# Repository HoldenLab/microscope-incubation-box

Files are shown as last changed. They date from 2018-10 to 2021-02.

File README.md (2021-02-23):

## This box has been superseded by the LifeHack repository (Incubation Box). Documentation is available on the <a href="https://holdenlab.github.io/LifeHackWebsite/">LifeHack website</a>.

Microscope incubation box for home built single molecule microscope.
Designed in AutoDesk CAD software.

Designed by Dr Yann Cesbron, Holden Lab

We heat this system with a high precision temperature control system, "The Cube" from http://lis.ch/, which we have found to be stabe to < 0.1C.

The body plastic is 10mm Black 9961 Perspex and the Front Panel Top Window is 10mm Clear Perspex.

Fabrication was by a local company, Bay Plastics Ltd, North Shields, UK and cost £1350 inc. materials. 

See LICENSE.txt for license information.

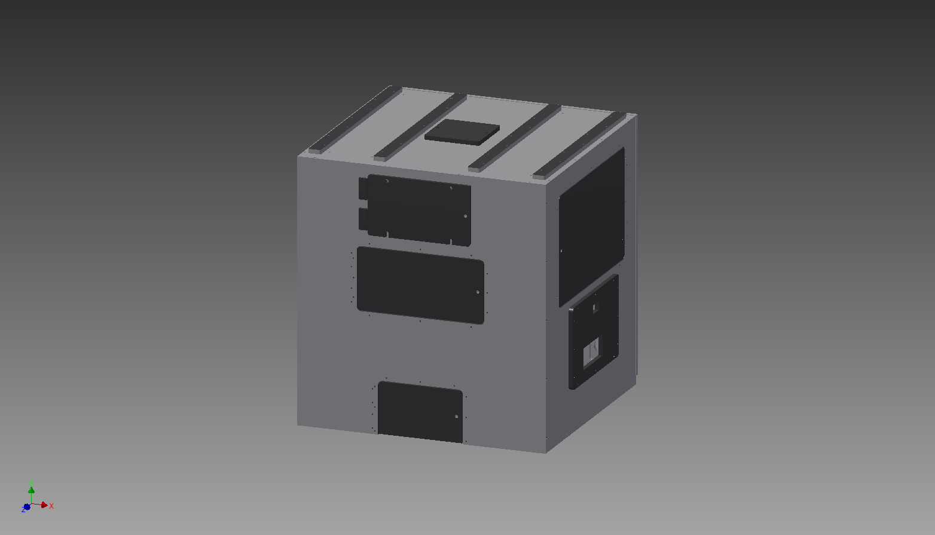
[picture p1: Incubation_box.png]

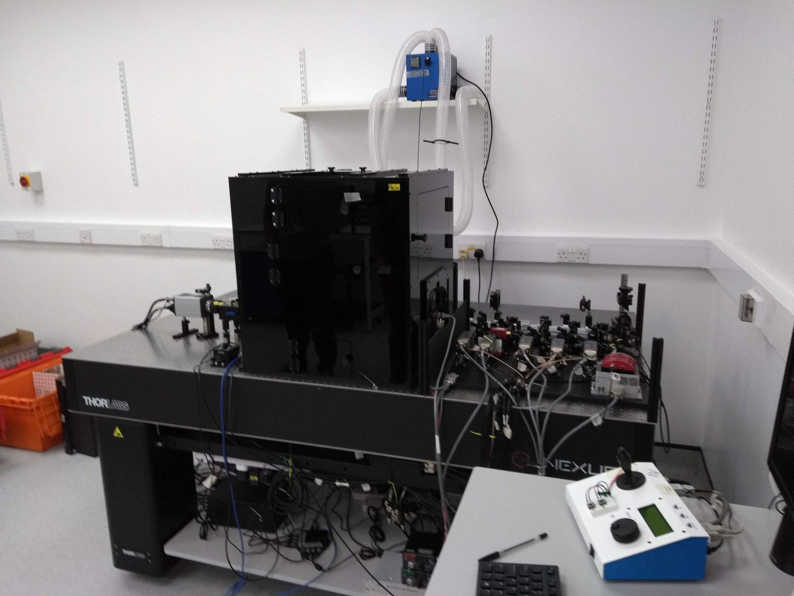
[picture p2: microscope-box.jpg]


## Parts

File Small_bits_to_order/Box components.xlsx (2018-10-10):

Component | Price | Screw | Company | Stock no.
Southco Black Nylon Torque-Adjustable Hinge Screw, 49mm x 44mm x 7mm | £8.34 | 4.5 mm | RS | 268-2086
Eclipse 5mm Neodymium Disc Magnet | £5.24 | Magnet diameter: 5mm/ Length: 2mm | RS | 792-4559
Elesa Black Polymer Knob 69893, M6 x 18 | £1.71 | M6 screw Thread | RS | 290-3743
HI-TORQUE Stainless Steel with Slotted Hex Head Hose Clip Worm Drive, 16mm Band Width, 50mm - 70mm Inside Diameter | £4.85 |  | RS | 494-2172
White extruded PVC sheet 2mm thickness (2440m x 1220 mm) (020XTPVCWHITE) | £30.87 |  | Bay Plastics Ltd
Black Natural Rubber Sheets, 1000mm x 600mm x 1.5mm | £9.08 |  | RS | 506-3078
50 x 20mm 2 Hole Steel Angle Bracket, 2mm Thickness | £2.26 | 4.5 mm screw holes (needs enlarging) | RS | 387-4028
15 x 25mm 2 Hole Steel Angle Bracket, 1.2mm Thickness | £0.23 | 3.7mm screw holes (may need enlarging) | RS | 427-997
RS Pro Clear Passivated, Zinc Steel Self-Clinching Nut, M4 | £6.16 | M4 holes | RS | 827-647
RS Pro Steel Zinc Plated Self-Clinching Standoff, M4 | £25.04 | M4 holes | RS | 827-518
RS Pro Brass Insert, M4 | £15.10 | M4 holes | RS | 278-607

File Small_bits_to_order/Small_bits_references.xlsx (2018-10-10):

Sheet: Materials_list_small_bits
 |  | Supplier | Ref | Name | Unit price | # |  |  | Note: where
Hinges
 |  | RS | 268-2086 | Southco Black Nylon Torque-Adjustable Hinge Screw, 49mm x 44mm x 7mm | 8.34 | 10 | 83.4 |  | Front: 3x2; left: 2; right: 2
 |  |  |  |  |  |  | 0
Door knob
 | option 1 | RS | 448-8858 | Elesa Black Polymer Knob, M6 x 12 | 1.327 | 10 | 13.27 |  | M6
 | option 2 | RS | 686-020 | RS Pro Black Duroplast Knob | 0.846 |  | 0 |  | M6
 | option 3 | RS | 290-3743 | Elesa Black Polymer Knob 69893, M6 x 18 | 1.708 |  | 0 |  | nope, too big
 | option 4 | RS | 448-8820 | Elesa Black Polymer Knob, M4 x 10 | 1.192 |  | 0 |  | M4
 | option 5 | RS | 448-8820 | Elesa Black Polypropylene (PP) Knob 26661, M4 x 8 | 4.75 |  | 0 |  | M4
Cover knobs
 |  | RS | 702-7557 | RS Pro Duroplast Knob, M6 x 20 | 1.587 | 10 | 15.87 |  | Front: 4; top: 2
 |  |  |  |  |  |  | 0
 |  |  |  |  |  |  | 0
Door screws |  |  |  |  |  |  | 0
 |  | RS | 232-8467 | Hex Socket Countersunk Stainless Steel Plain Socket Screw, M6 x 16mm | 11.32 | 1 | 11.32 |  | Box of 50
Bracket
 |  | RS | 427-997 | 15 x 25mm 2 Hole Steel Angle Bracket, 1.2mm Thickness | 0.246 | 10 | 2.46
 |  | RS | 387-4028 | 50 x 20mm 2 Hole Steel Angle Bracket, 2mm Thickness | 2.26 | 4 | 9.04
 |  |  |  |  |  |  | 0
Rubber |  |  |  |  |  |  | 0
 |  | RS | 506-3163 | Black Neoprene Rubber Sheets, 1000mm x 600mm x 1.5mm | 7.86 | 1 | 7.86 |  | To go around side and back holes around optics/electronics
 |  | RS | 733-6731 | Black Neoprene Rubber Sponge, 1000mm x 2000mm x 1.5mm | 8.16 | 1 | 8.16 |  | To go around front top door
 |  | RS | 506-3078 | Black Natural Rubber Sheets, 1000mm x 600mm x 1.5mm | 9.08 | 1 | 9.08
Magnets
 |  | RS | 846-3806 | Eclipse 6mm Alnico Deep Pot Magnet | 6.42 | 2 |  |  | Front top door (sold by pairs)
 |  | RS
TO DO |  |  |  | Select magnets for all doors |  |  |  | See here | http://uk.rs-online.com/web/c/fasteners-fixings/magnets-magnetic-strips/magnets/ Force&sort-order=asc
 |  |  |  |  |  |  |  |  | http://uk.rs-online.com/web/c/fasteners-fixings/magnets-magnetic-strips/magnets/ Force&sort-order=asc&applied-dimensions=4292097422,4293386241,4293621427,4294468586,4294469893,4294469897,4294469899,4294471116,4294471118,4294471882,4294471899,4294471903,4294471925,4294471926,4294471928,4294471931,4294472823
 |  |  |  |  |  |  |  | Maybe this one? | http://uk.rs-online.com/web/p/magnets/6679977/
 |  |  |  |  |  |  |  |  | http://uk.rs-online.com/web/p/magnets/7924559/?searchTerm=792-4559

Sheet: Sheet1
Front | 610 | 565 | 0.61 | 0.565 | 0.34465
Back | 620 | 585 | 0.62 | 0.585 | 0.3627
Left | 610 | 550 | 0.61 | 0.55 | 0.3355
Right | 610 | 550 | 0.61 | 0.55 | 0.3355
Top | 585 | 550 | 0.585 | 0.55 | 0.32175
 |  |  |  |  | 1.7001
 |  |  |  |  |  | 2.03 | 1.525 | 3.09575
 |  |  |  |  |  | 3.05 | 2.03 | 6.1915

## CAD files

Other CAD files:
Individual_parts/L1_main.dwg
Individual_parts/R1_main.dwg
Individual_parts/T1_main.dwg
Individual_parts/F1_main.dwg
Individual_parts/B1_main.dwg
Individual_parts/F5_top_door_window.dwg
Individual_parts/F7_middle_door_left_flange_1.dwg
Individual_parts/F14_bottom_door_bottom_flange_4.dwg
Individual_parts/L7_door_flange_4_right.dwg
Individual_parts/F9_middle_door_bottom_flange_3.dwg
Individual_parts/F11_bottom_door_left_flange_1.dwg
Individual_parts/F16_middle_door_magnet_flange.dwg
Individual_parts/B4_bottom_air_duct_flange.dwg
Individual_parts/R8_door_magnet_flange.dwg
Individual_parts/F6_top_door_hinges_2spacers.dwg
Individual_parts/L3_Emission_flange.dwg
Individual_parts/T3_flanges.dwg
Individual_parts/F2_top_door.dwg
Back_flanges.ipt
Back_part.ipt
Front_part.ipt
Incubation_box.iam
Incubation_box.ipn
Individual_parts/B1_main.ipt
Individual_parts/B2_opening_cover.dwg
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

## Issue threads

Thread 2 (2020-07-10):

Add microscope incubation box to open-neuroscience.com

amchagas, 2020-07-10:
Hi!

We are reaching out because we would love to have your project listed on [Open Neuroscience](<https://open-neuroscience.com>), and also share information about this project:

Open Neuroscience is a community run project, where we are curating and highlighting open source projects related to neurosciences!

Briefly, we have a website where short descritptions about projects are listed, with links to the projects themselves, their authors, together with images and other links.

Once a new entry is made, we make a quick check for spam, and publish it.

Once published, we make people aware of the new entry by [Twitter](https://twitter.com/openneurosci) and a [Facebook](https://www.facebook.com/OpenNeuroscience) group.

**To add information about their project, developers only need to fill out this [form](https://forms.gle/ByM8thAhZJkHBMQN8)**

In the form, people can add subfields and tags to their entries, so that projects are filterable and searchable on the website!

The reason why we have the form system is that it makes it open for everyone to contribute to the website and allows developers themselves to describe their projects!

Also, there are so many amazing projects coming out in Neurosciences that it would be impossible for us to keep track and log them all!

Please [get in touch](mailto:openeuroscience@gmail.com) if you have any questions or would like to collaborate!

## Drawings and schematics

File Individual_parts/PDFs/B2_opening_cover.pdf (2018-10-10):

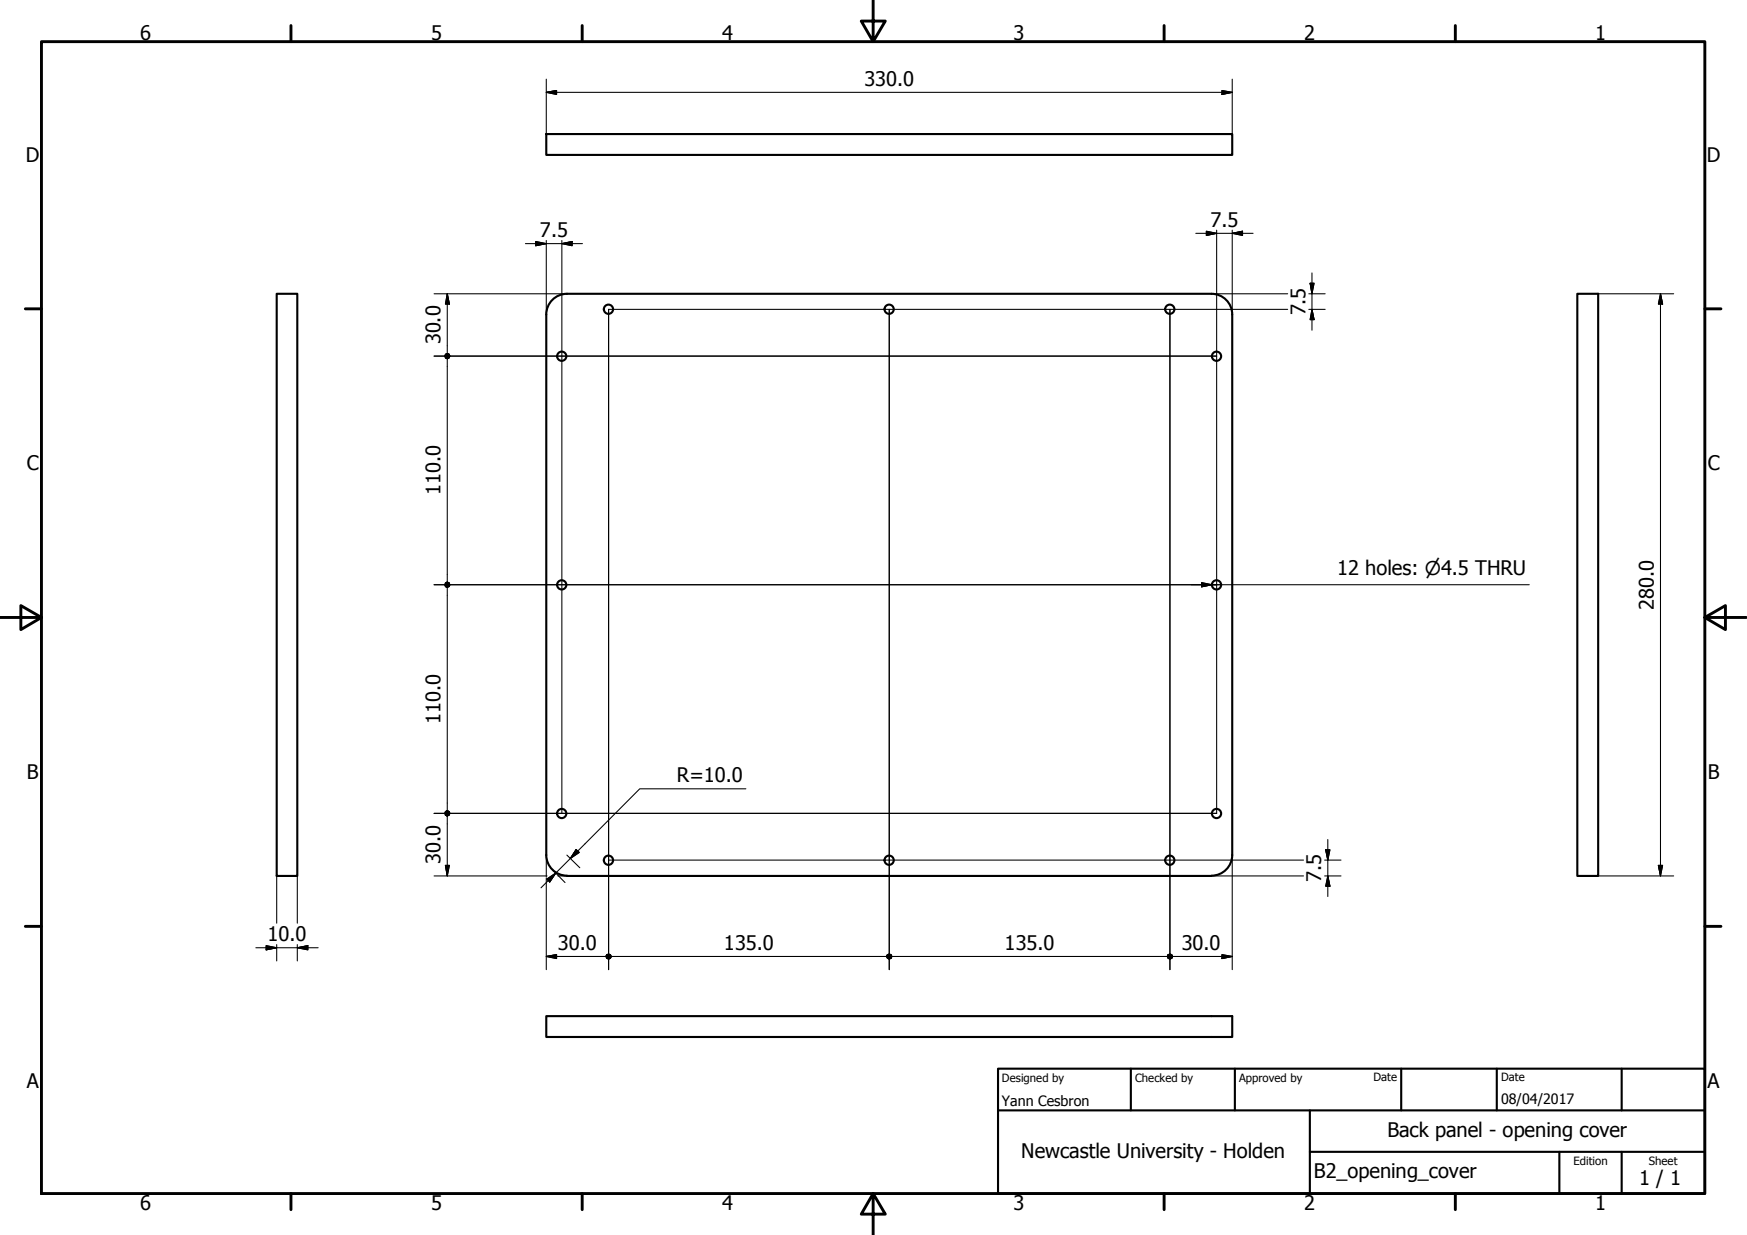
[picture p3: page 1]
B2_opening_cover; Yann Cesbron; Designed by; Checked by; Approved by; Date; Edition; Sheet; 12 holes: P4.5 THRU

Back panel - opening cover

Newcastle University - Holden

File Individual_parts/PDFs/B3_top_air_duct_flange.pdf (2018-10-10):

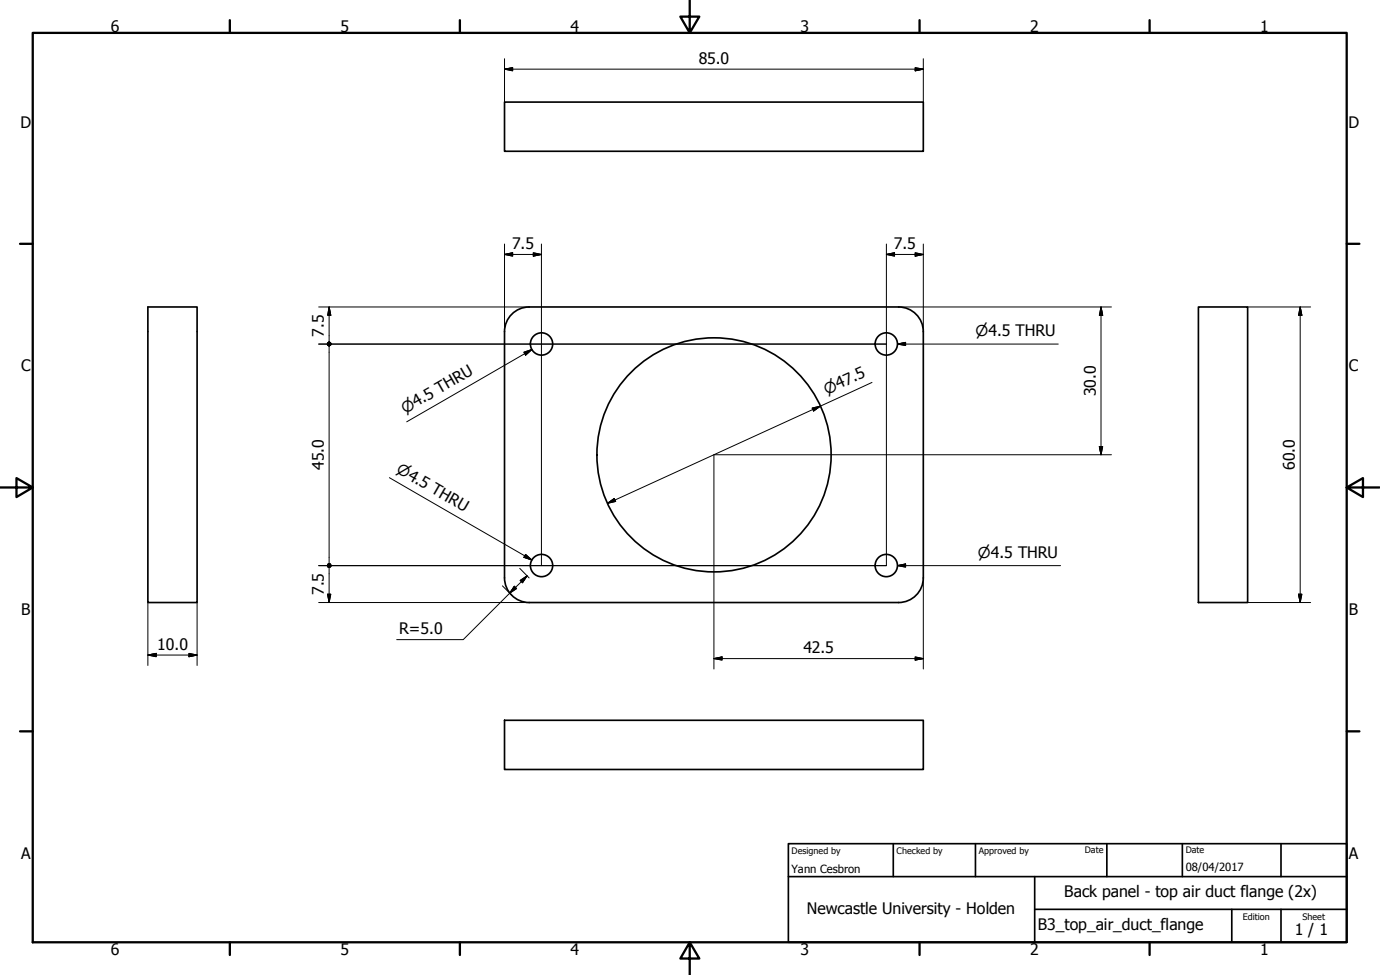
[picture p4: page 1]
B3_top_air_duct_flange; Yann Cesbron; Designed by; Checked by; Approved by; Date; Edition; Sheet; P4.5 THRU

Back panel - top air duct flange (2x)

Newcastle University - Holden

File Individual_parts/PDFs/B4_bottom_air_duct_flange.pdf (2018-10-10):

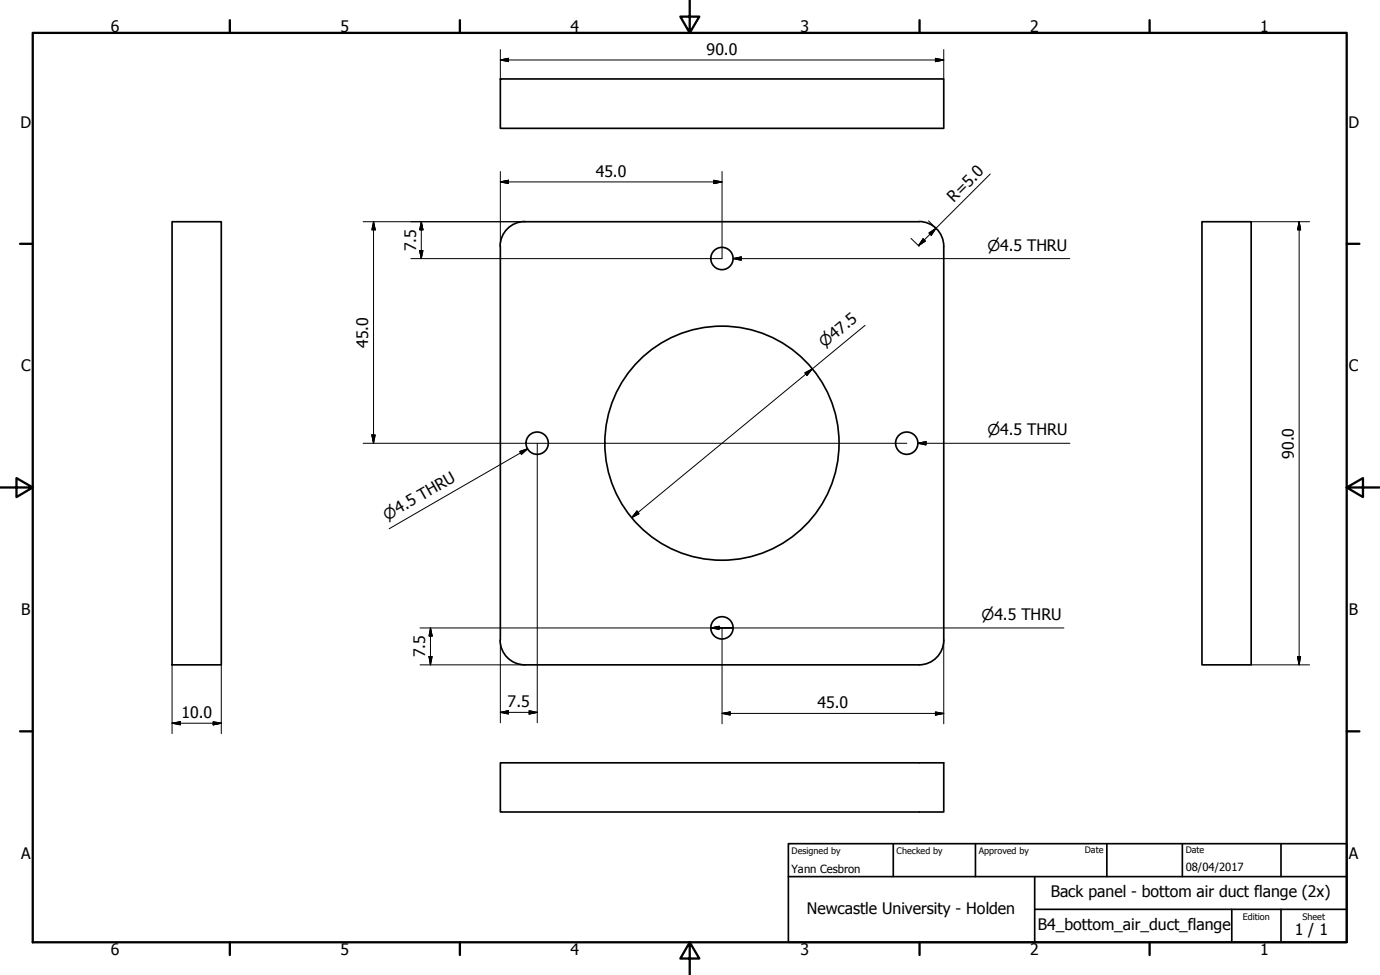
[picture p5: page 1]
B4_bottom_air_duct_flange; Yann Cesbron; Designed by; Checked by; Approved by; Date; Edition; Sheet; P4.5 THRU

Back panel - bottom air duct flange (2x)

Newcastle University - Holden

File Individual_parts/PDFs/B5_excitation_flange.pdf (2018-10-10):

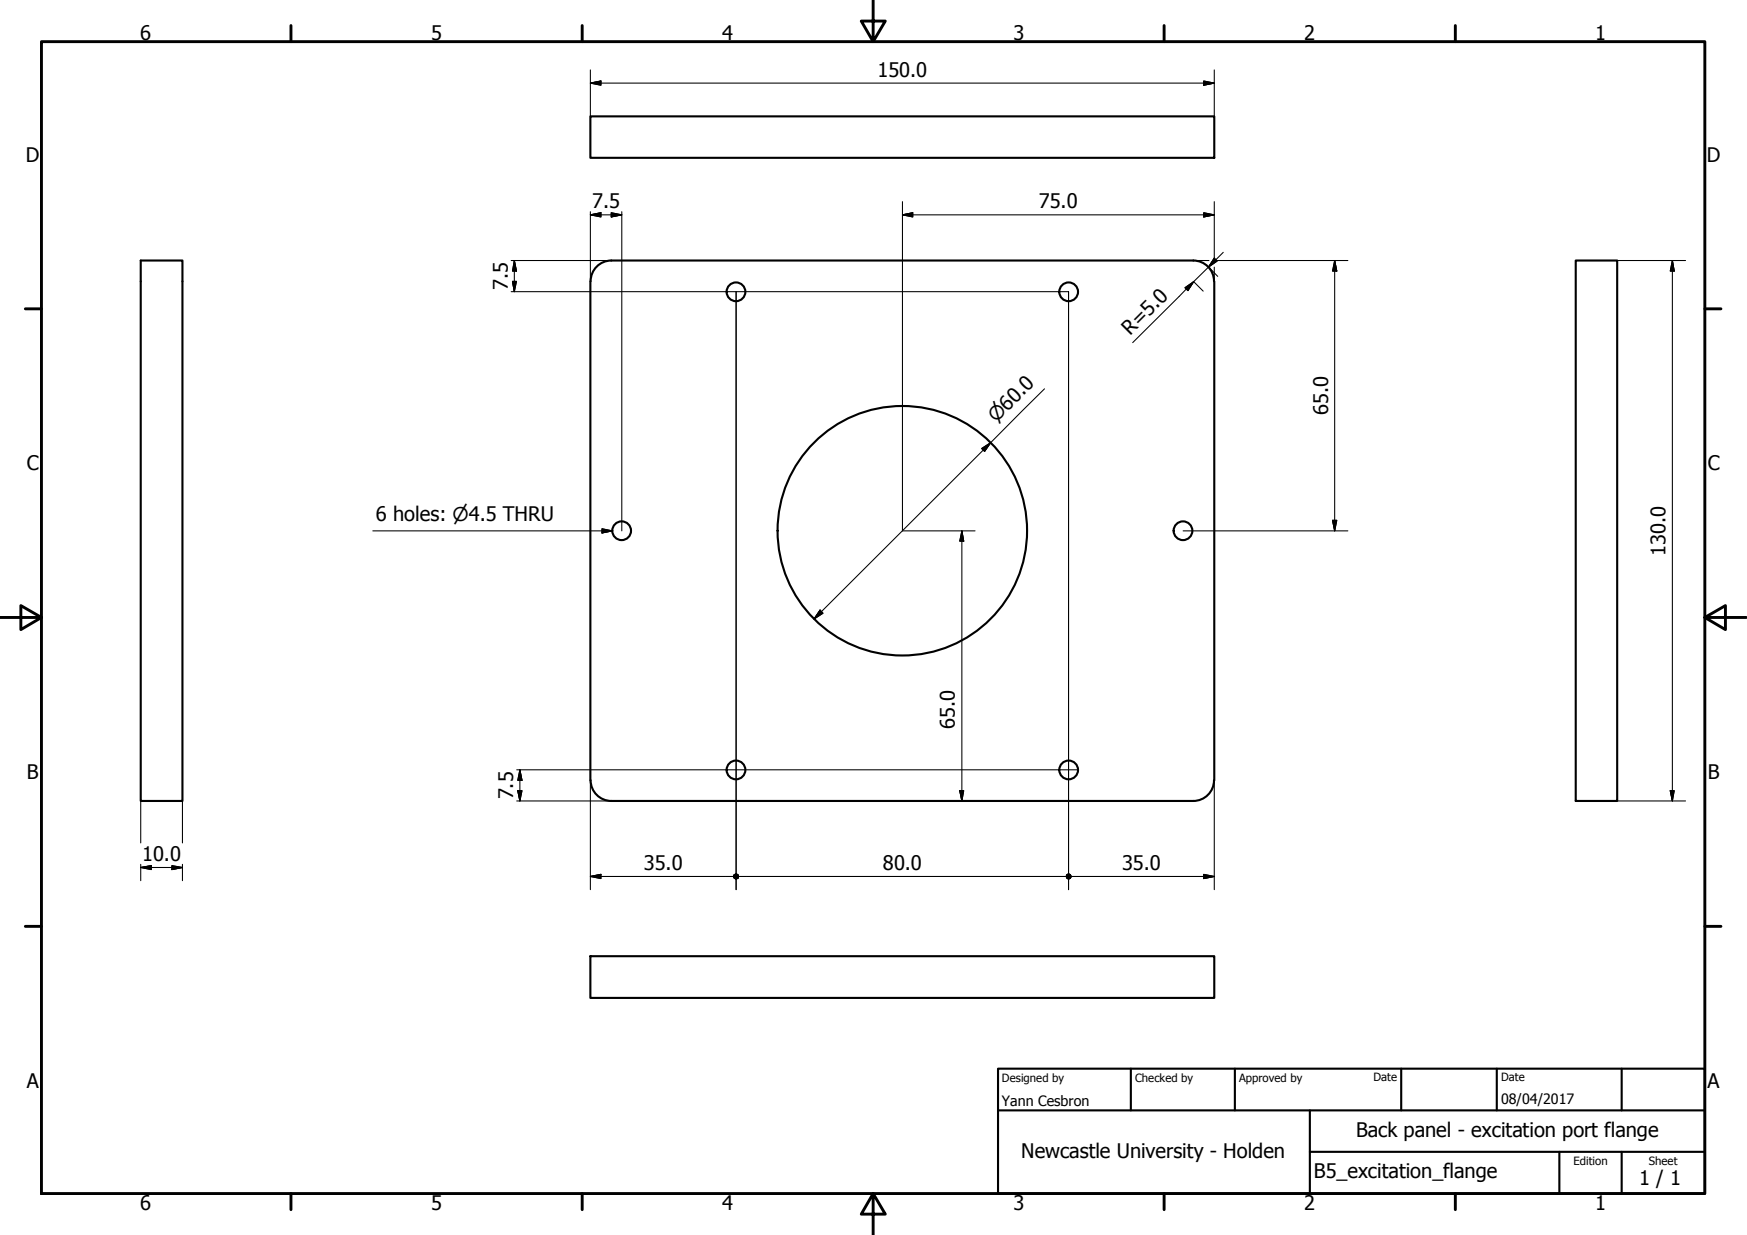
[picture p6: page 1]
B5_excitation_flange; Yann Cesbron; Designed by; Checked by; Approved by; Date; Edition; Sheet; 6 holes: P4.5 THRU

Back panel - excitation port flange

Newcastle University - Holden

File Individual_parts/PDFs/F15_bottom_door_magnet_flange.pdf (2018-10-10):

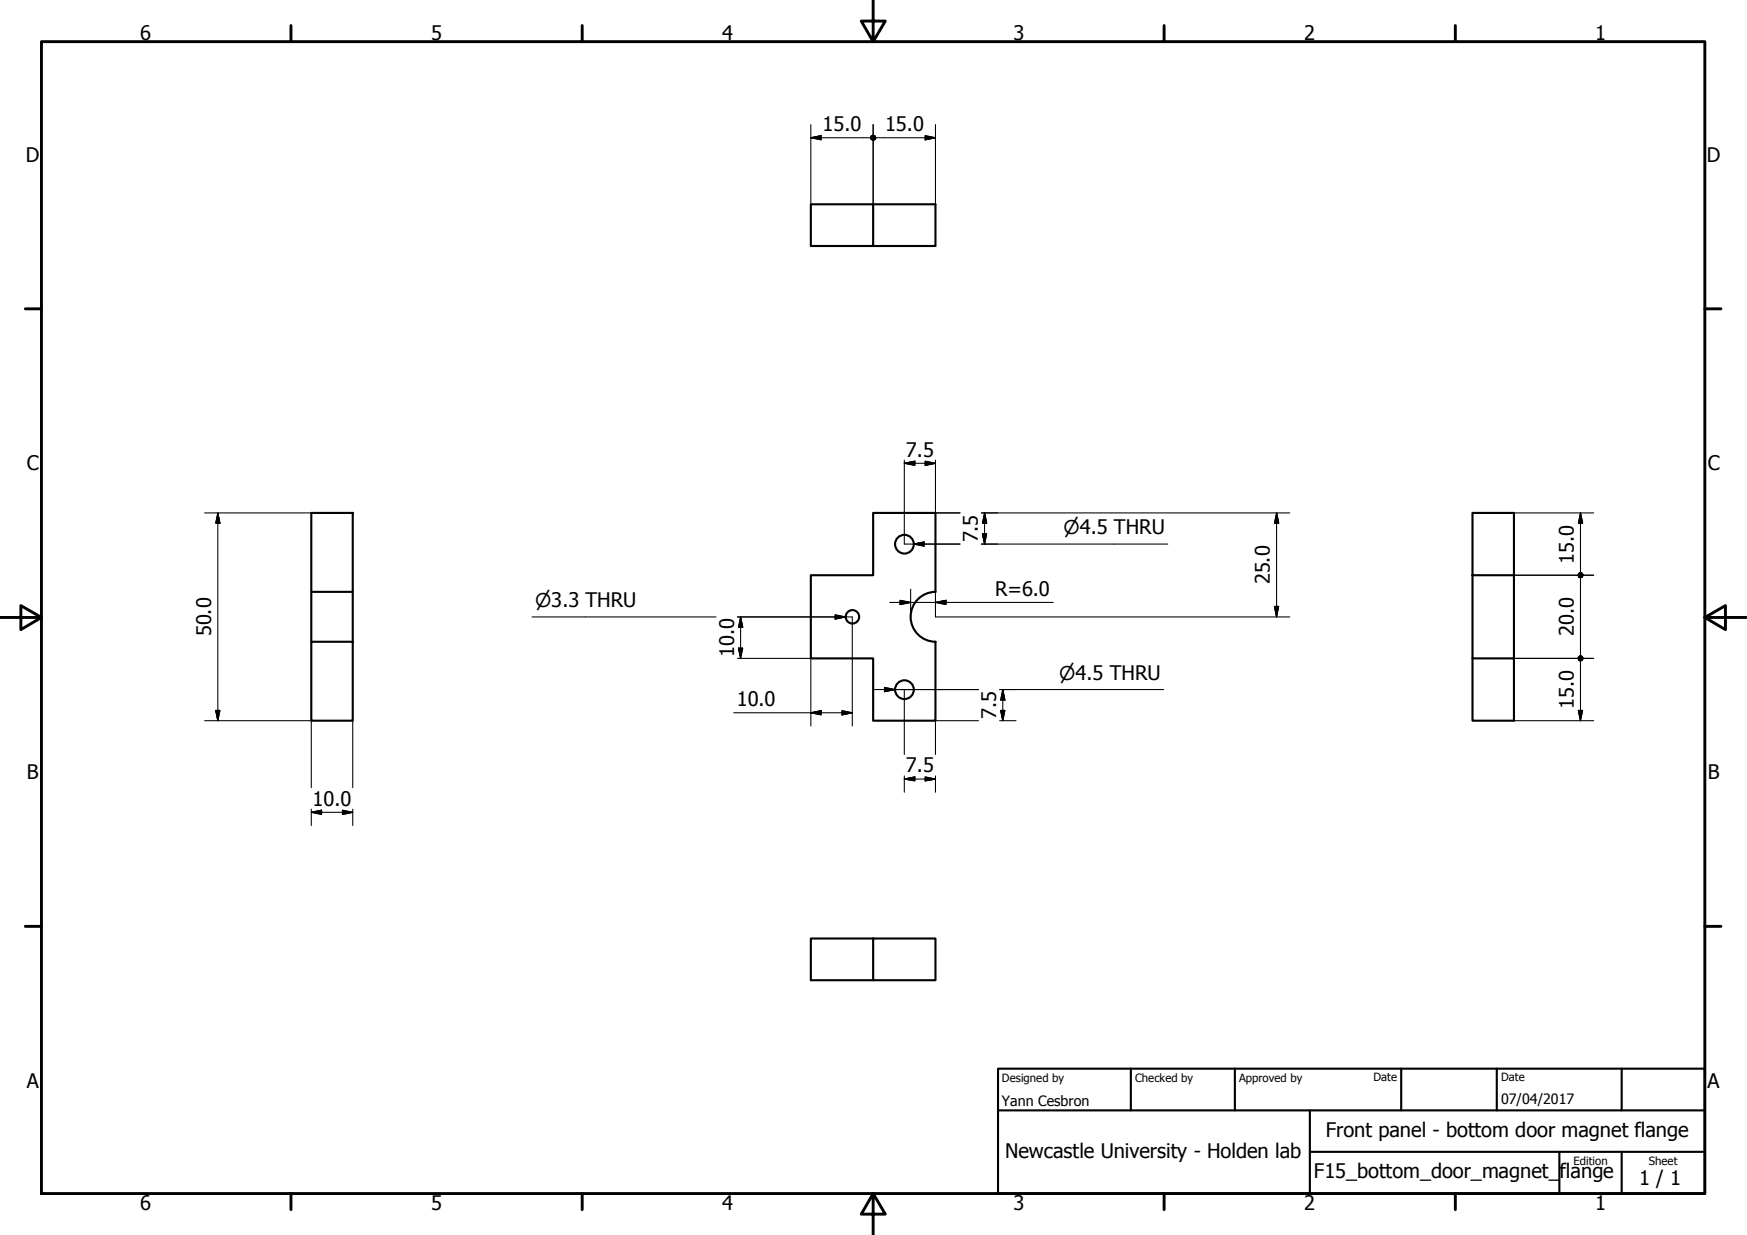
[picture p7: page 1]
F15_bottom_door_magnet_flange; Yann Cesbron; Designed by; Checked by; Approved by; Date; Edition; Sheet; P4.5 THRU; P3.3 THRU

Front panel - bottom door magnet flange

Newcastle University - Holden lab

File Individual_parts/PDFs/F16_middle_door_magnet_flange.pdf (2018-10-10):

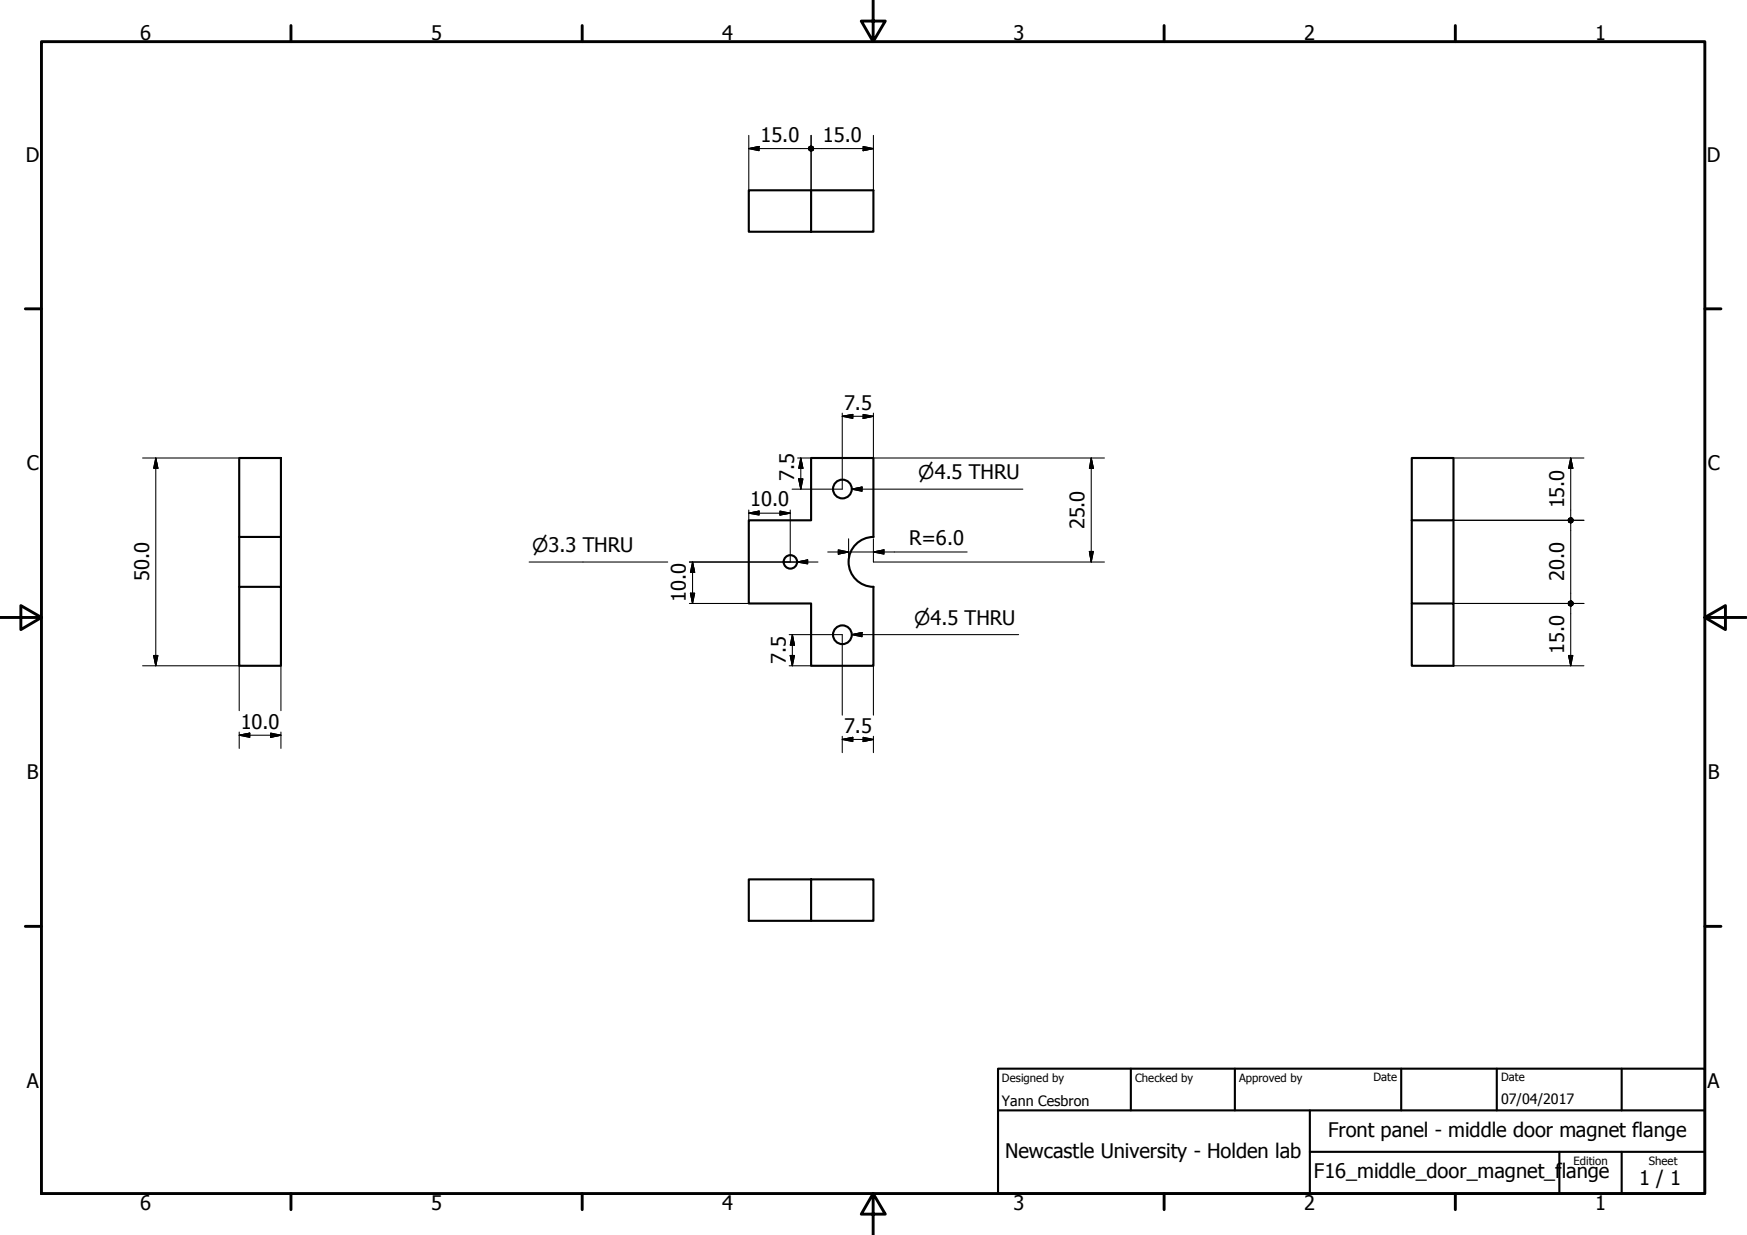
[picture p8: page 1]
F16_middle_door_magnet_flange; Yann Cesbron; Designed by; Checked by; Approved by; Date; Edition; Sheet; P4.5 THRU; P3.3 THRU

Front panel - middle door magnet flange

Newcastle University - Holden lab

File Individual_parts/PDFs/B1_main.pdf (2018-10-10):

P
P

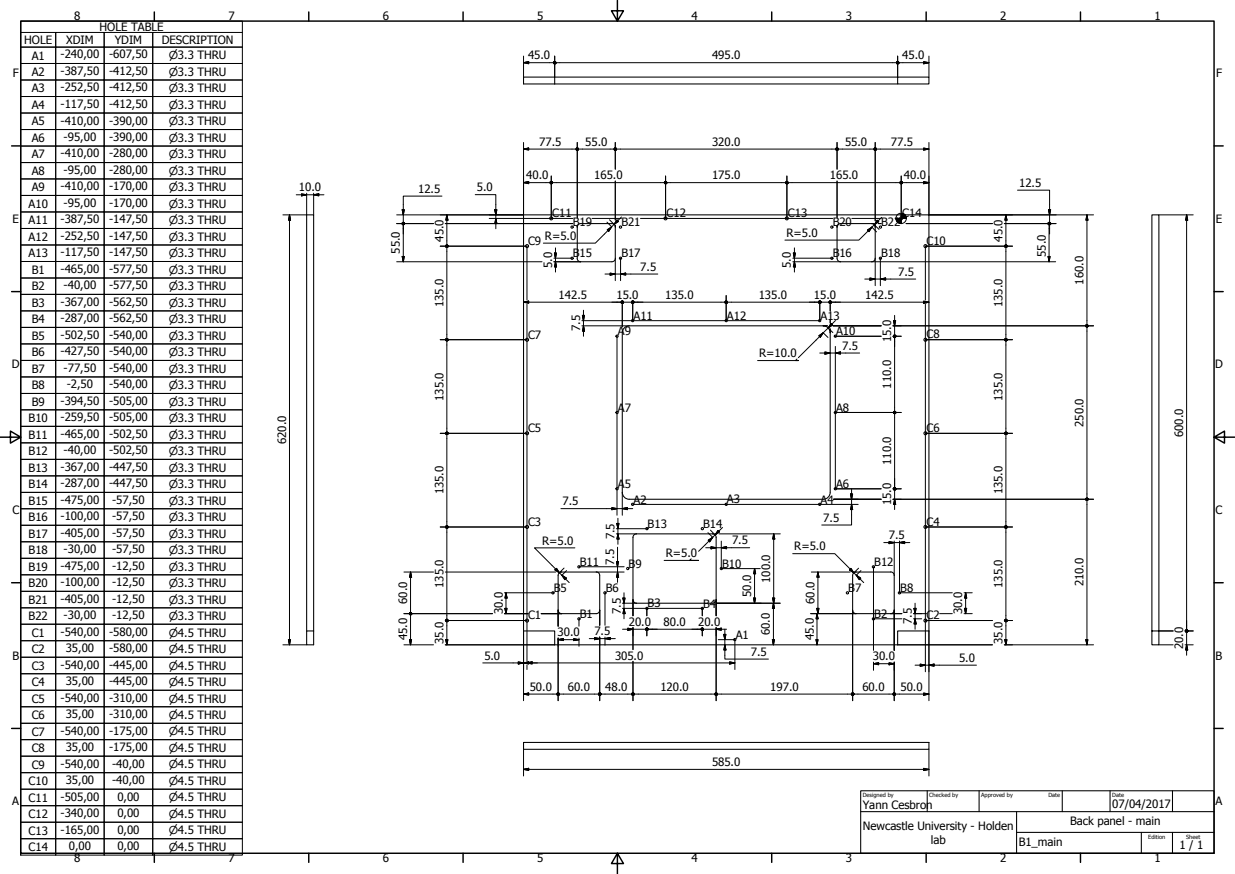
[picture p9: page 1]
tle; old; n lab

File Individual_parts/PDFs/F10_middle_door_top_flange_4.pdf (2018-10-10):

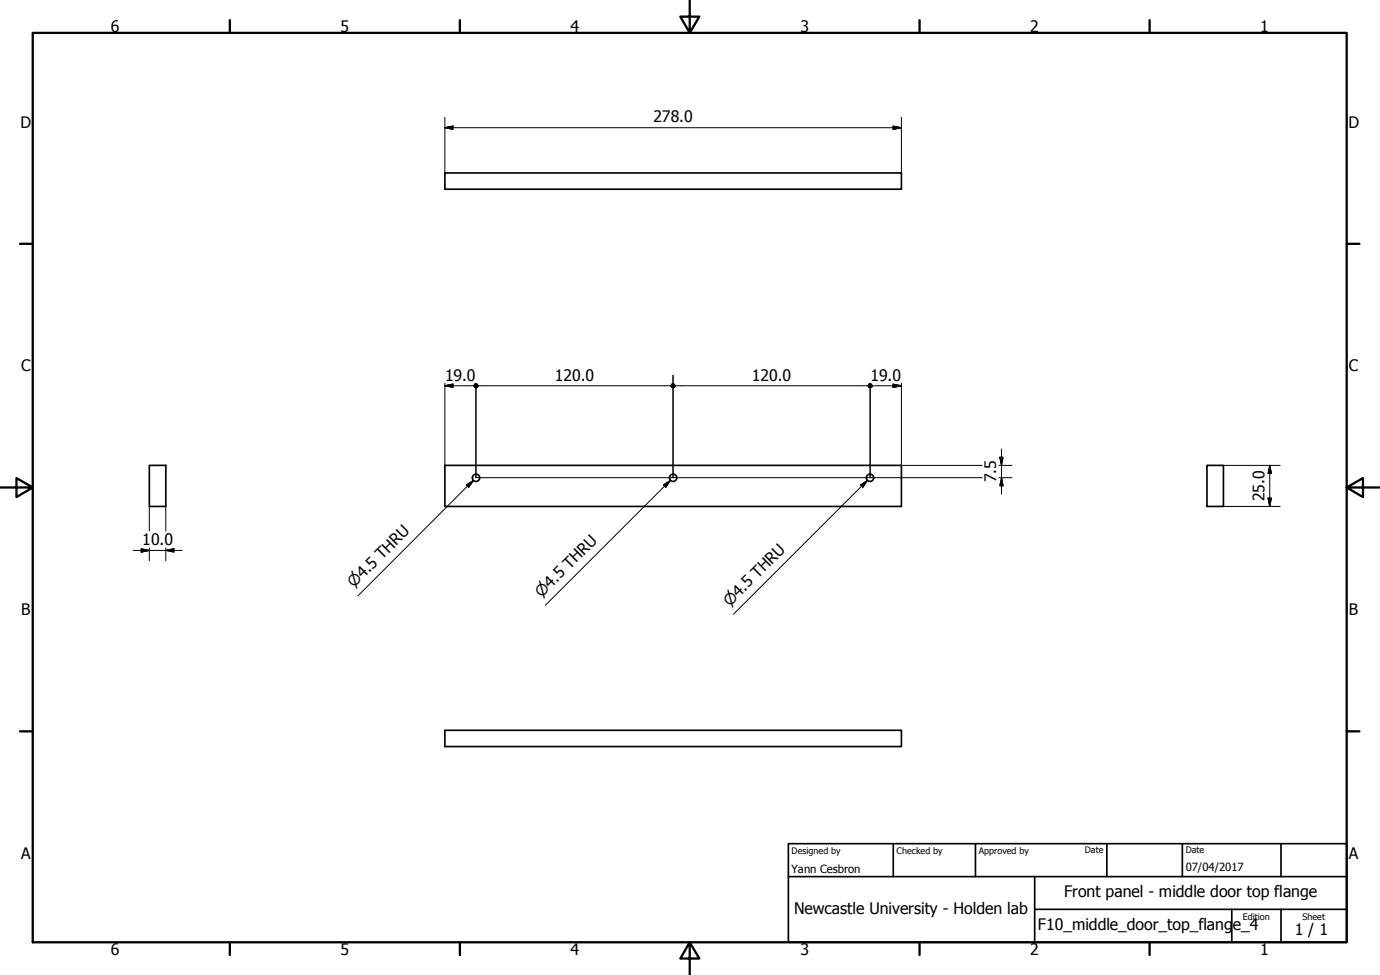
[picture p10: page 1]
F10_middle_door_top_flange_4; Yann Cesbron; Designed by; Checked by; Approved by; Date; Edition; Sheet; P4.5 THRU

Front panel - middle door top flange

Newcastle University - Holden lab

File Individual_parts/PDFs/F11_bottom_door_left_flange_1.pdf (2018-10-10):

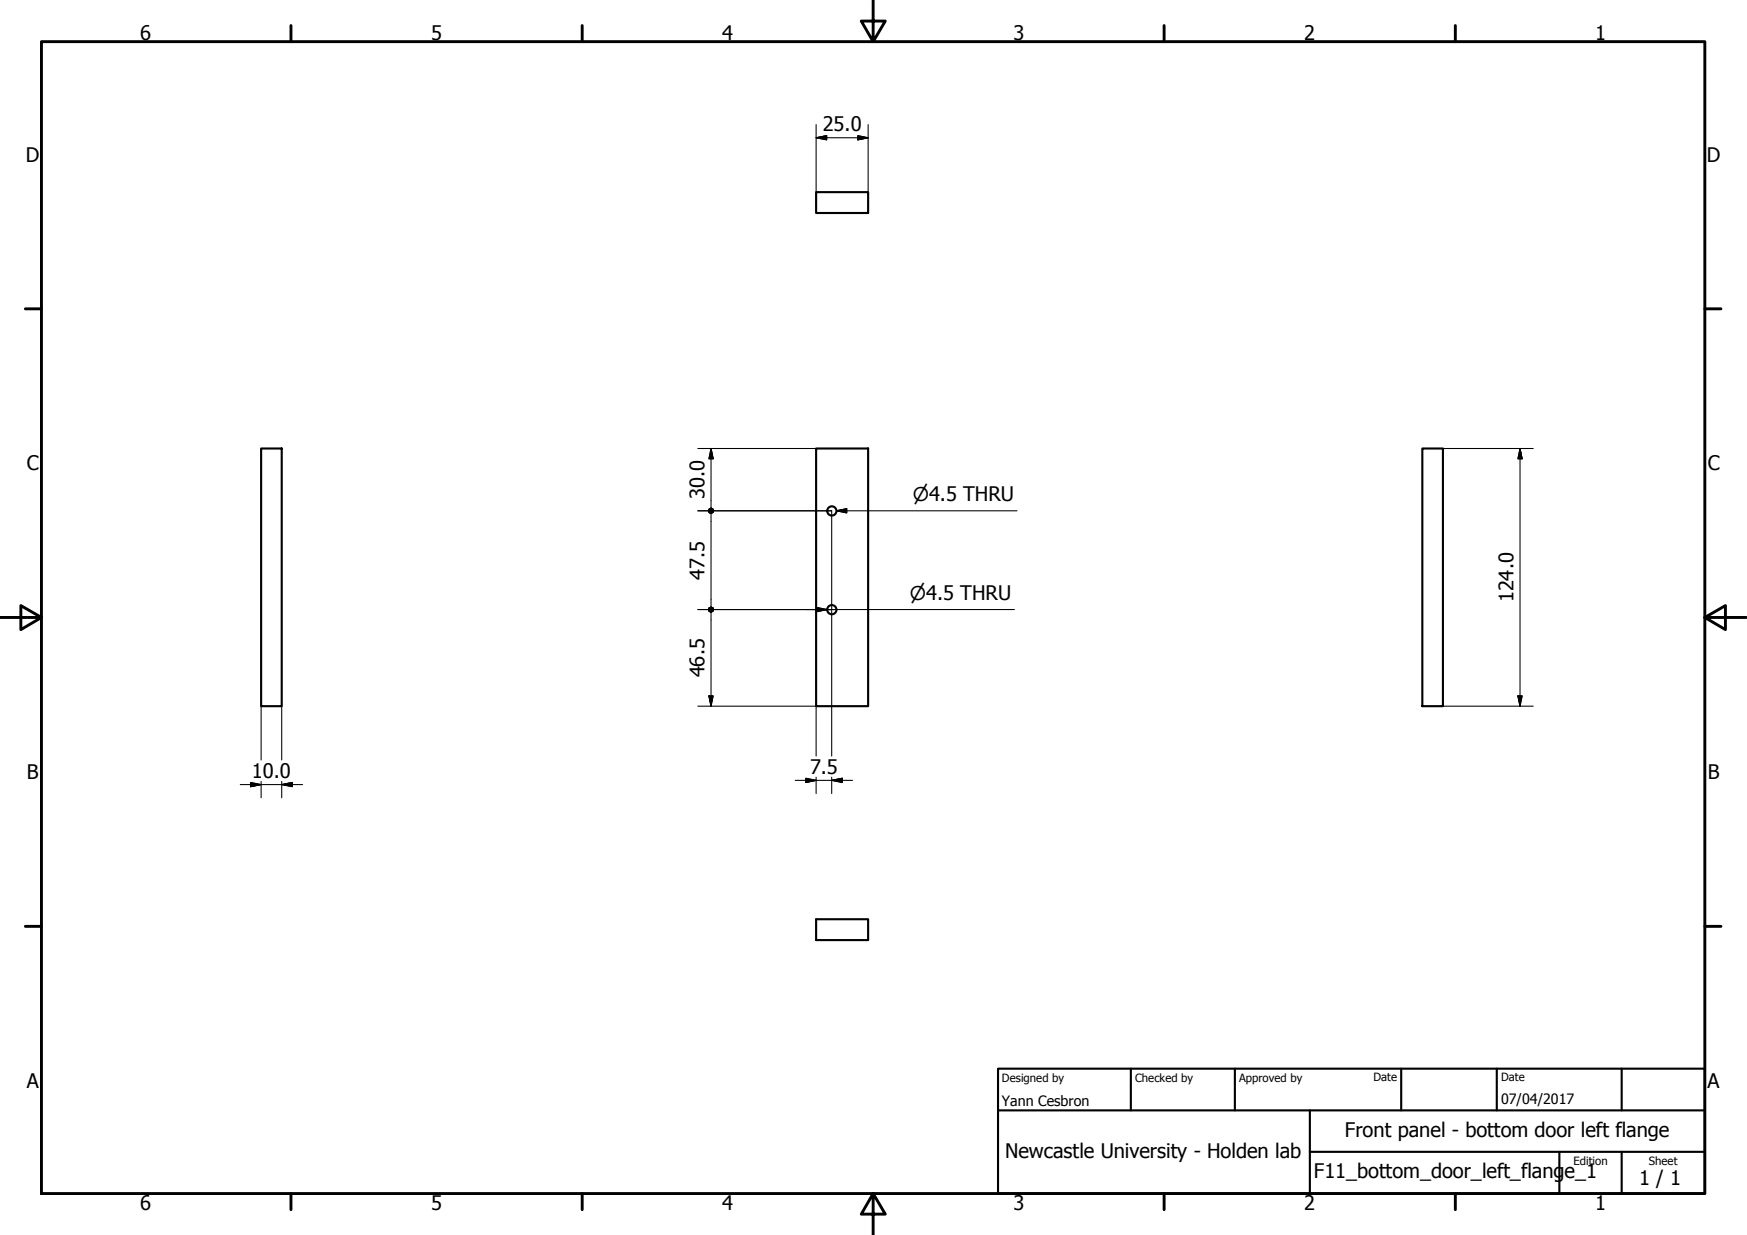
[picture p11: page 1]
F11_bottom_door_left_flange_1; Yann Cesbron; Designed by; Checked by; Approved by; Date; Edition; Sheet; P4.5 THRU

Front panel - bottom door left flange

Newcastle University - Holden lab

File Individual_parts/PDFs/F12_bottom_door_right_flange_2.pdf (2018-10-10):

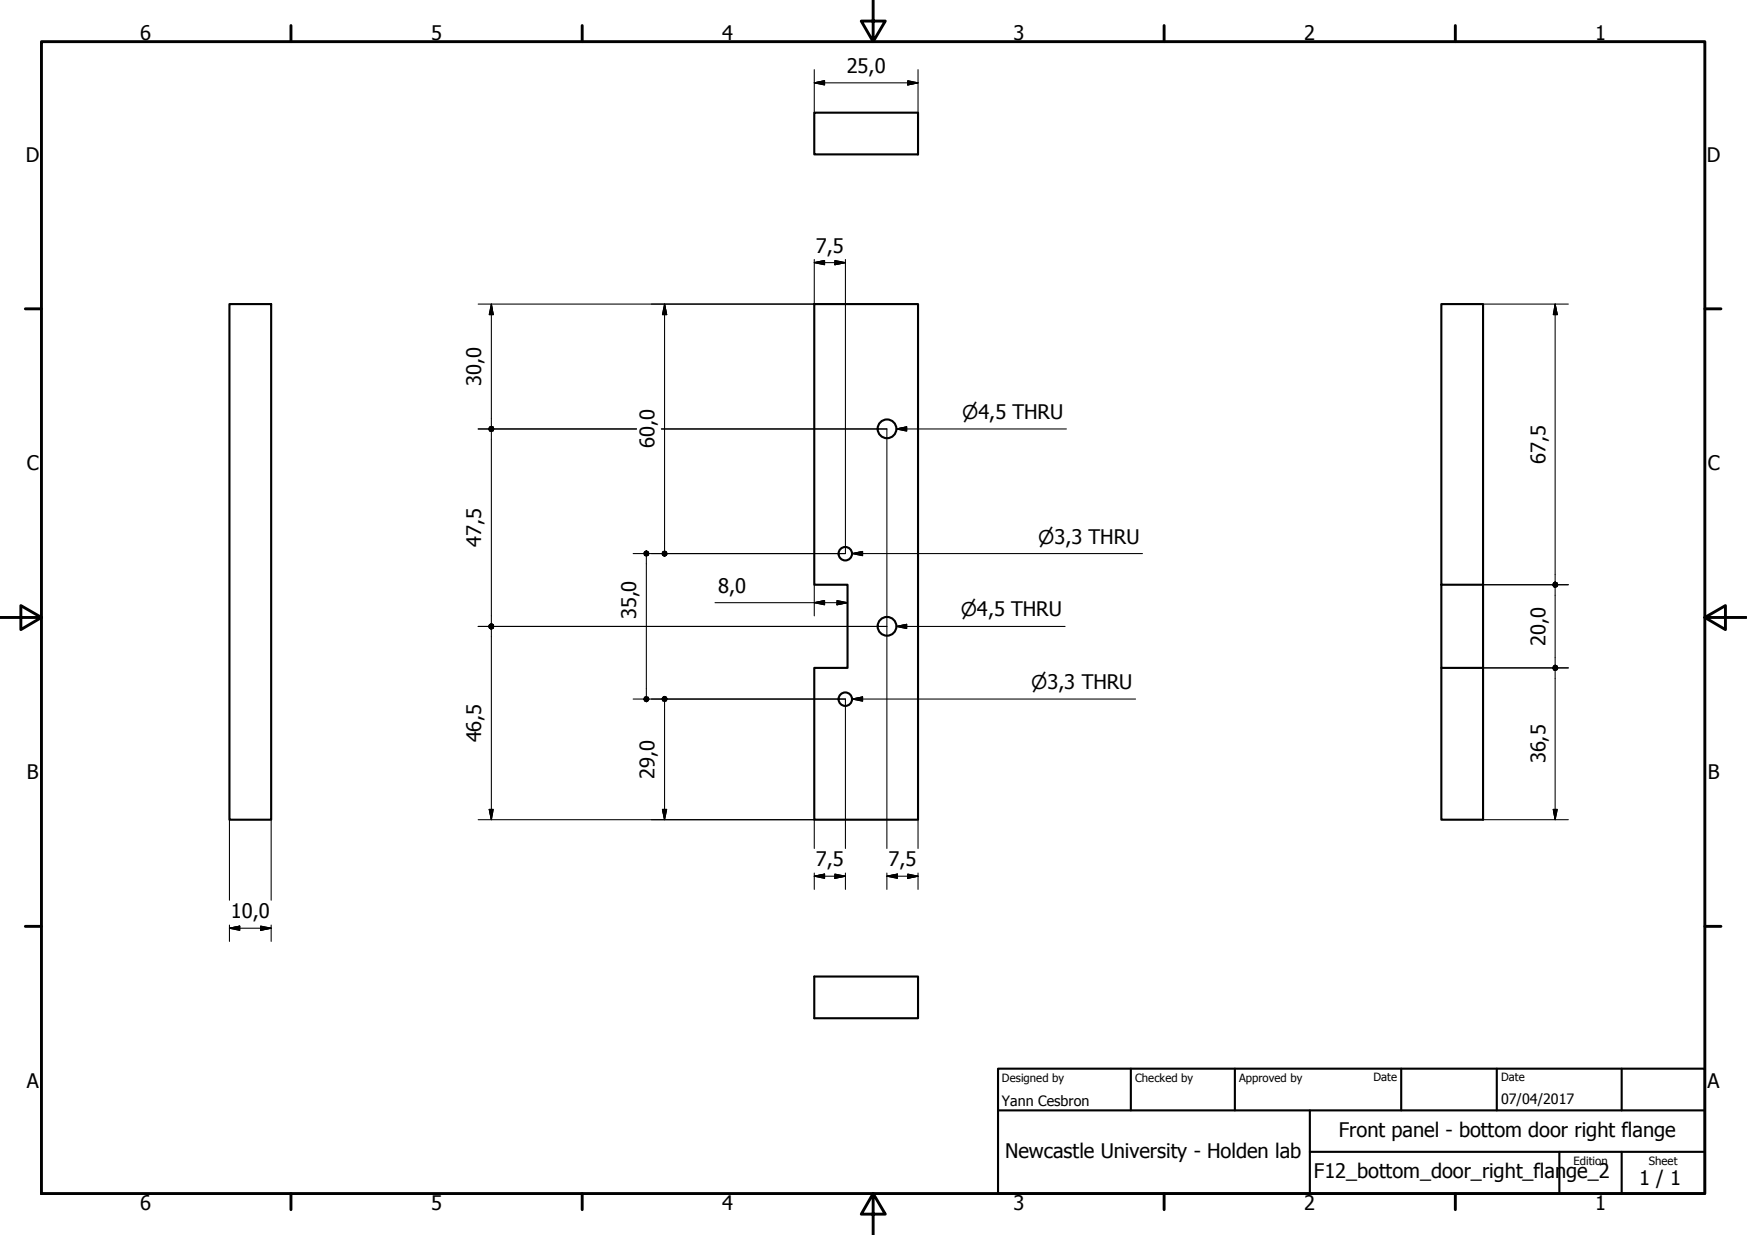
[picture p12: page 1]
F12_bottom_door_right_flange_2; Yann Cesbron; Designed by; Checked by; Approved by; Date; Edition; Sheet; P4,5 THRU; P3,3 THRU

Front panel - bottom door right flange

Newcastle University - Holden lab

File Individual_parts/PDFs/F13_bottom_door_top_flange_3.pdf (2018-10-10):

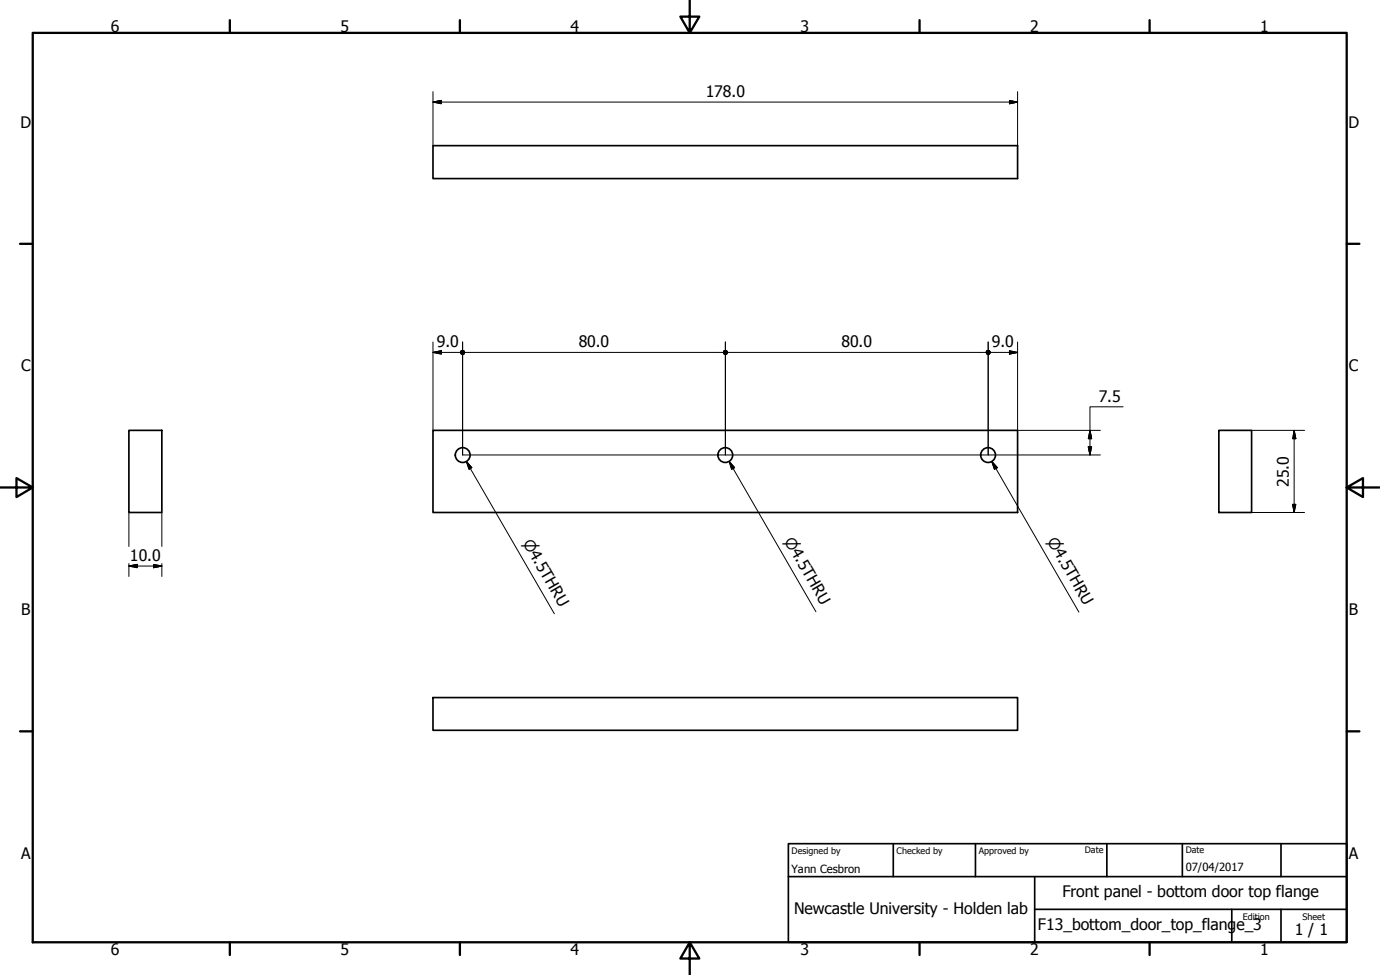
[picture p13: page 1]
F13_bottom_door_top_flange_3; Yann Cesbron; Designed by; Checked by; Approved by; Date; Edition; Sheet; P4.5THRU

Front panel - bottom door top flange

Newcastle University - Holden lab

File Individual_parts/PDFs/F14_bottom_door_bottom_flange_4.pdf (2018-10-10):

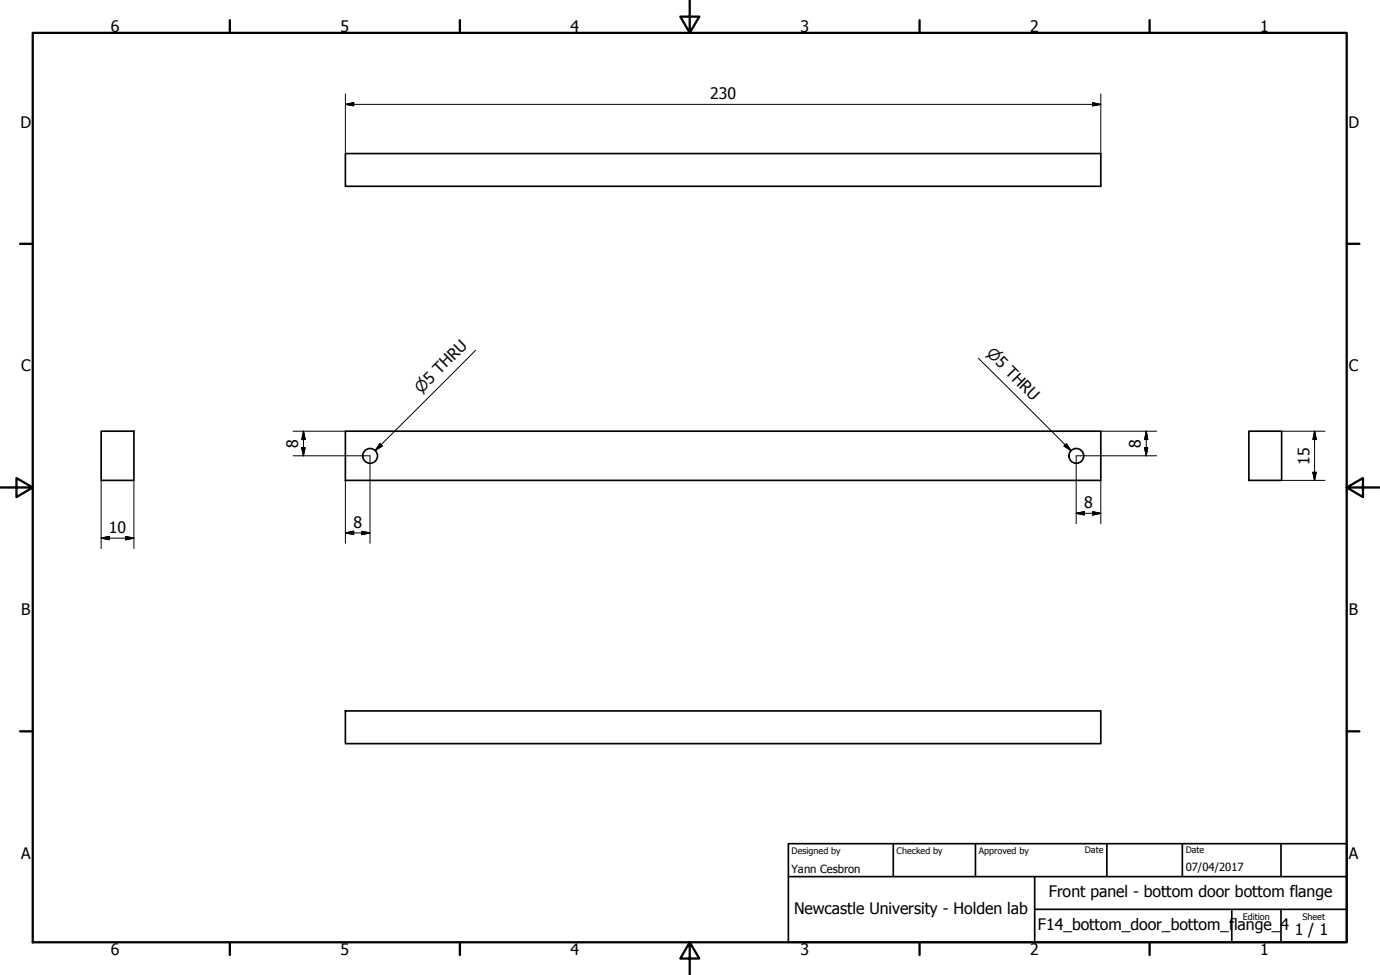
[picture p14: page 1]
F14_bottom_door_bottom_flange_4; Yann Cesbron; Designed by; Checked by; Approved by; Date; Edition; Sheet; P5 THRU

Front panel - bottom door bottom flange

Newcastle University - Holden lab

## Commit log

2018-10-10 Add the small parts list
    [Box components.xlsx, Small_bits_references.xlsx]
2018-10-10 Removed redundant OldVersions folder
    [Back_part.0053.ipt, Back_part_sketch.0002.idw, Back_part_sketch_2.0001.idw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]
